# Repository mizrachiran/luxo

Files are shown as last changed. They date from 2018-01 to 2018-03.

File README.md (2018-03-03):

# luxo switch

The luxo switch is an ESP8266 based switch which can control up to 2 appliances.
It was design to be integrate in existing setups where the module can be hidden behind existing wall switches to control light or outlets.
The board support 90-240v input and outputs.

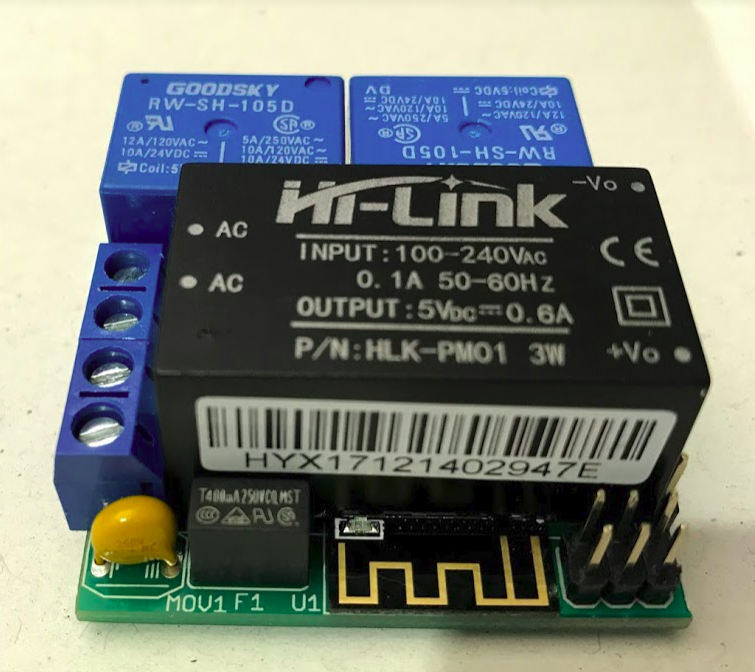
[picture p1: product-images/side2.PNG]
Luxo 1


[See more images](https://github.com/mizrachiran/luxo/tree/master/product-images)

# Software

Luxo support the following software:
* [Supla](https://www.supla.org/en/) - free cloud based open source software (offers ios & android apps)
* [Tasmota](https://github.com/arendst/Sonoff-Tasmota) - firmeware for controlling over MQTT

However, You can customize any ESP8266 open source project to work with the luxo switch

# Specification

* ESP8266 (ESP12E) WLAN module
* Wi-Fi 2.4GHz 802.11 b/g/n
* 90-240V I / O
* 2x outputs 10A, L switched
* 2x button connectors (to connect on \ off switches)
* Tempreture sensor input (DS18B20, DHT11 or DHT22)
* 1 ADC measurement input, e.g light intensity measurement from photoresistor
* 1 CFG button to enable the module into the configuration mode or assign custom action via software.
* 1 status LED
* Programming header pins (TX, RX, RST, 3.3v, GPIO0, GND)
* Size - 42 x 43 x 22 mm

# Schematic

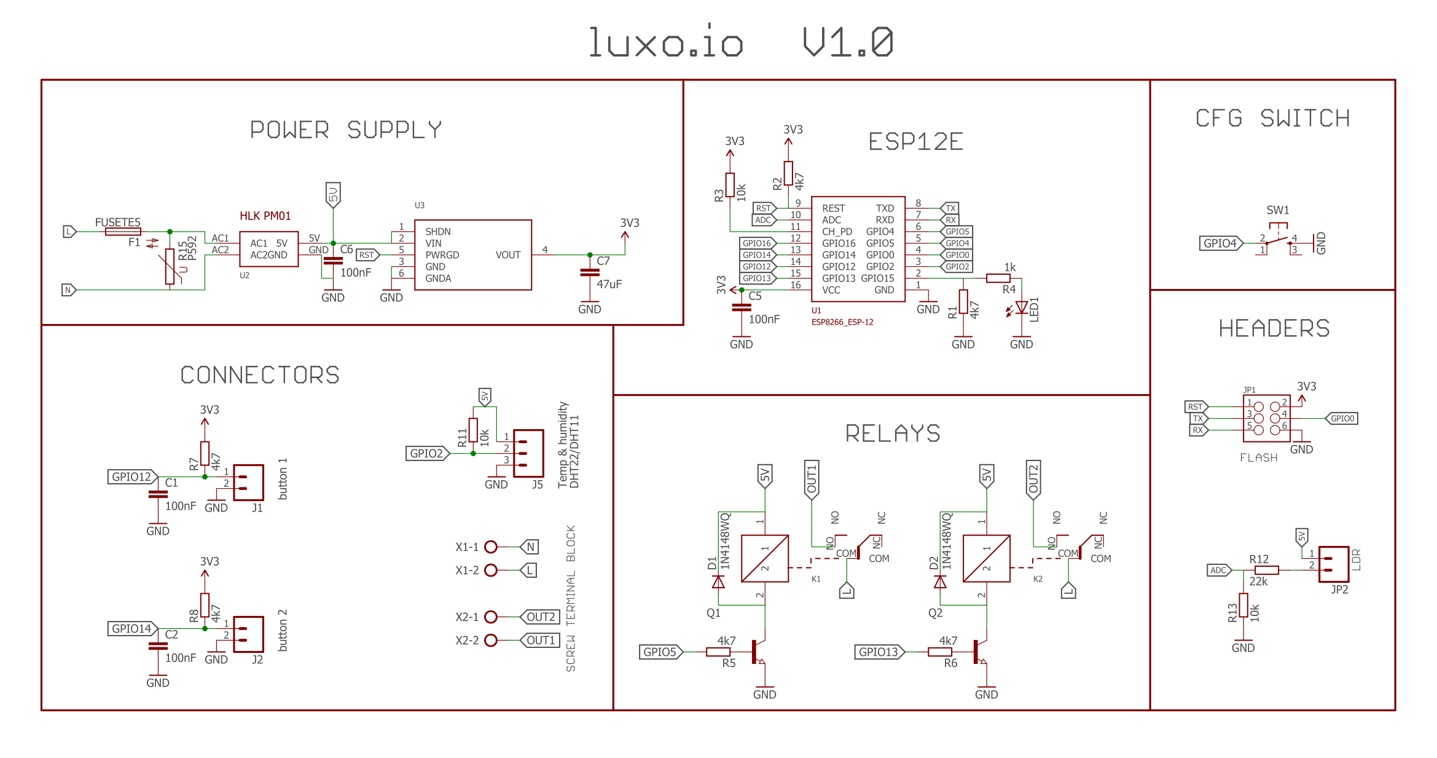
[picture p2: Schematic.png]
Luxo schematic


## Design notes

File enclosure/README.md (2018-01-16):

# Enclosure

[Open in Autodesk viewer](http://autode.sk/2DDgIPi)

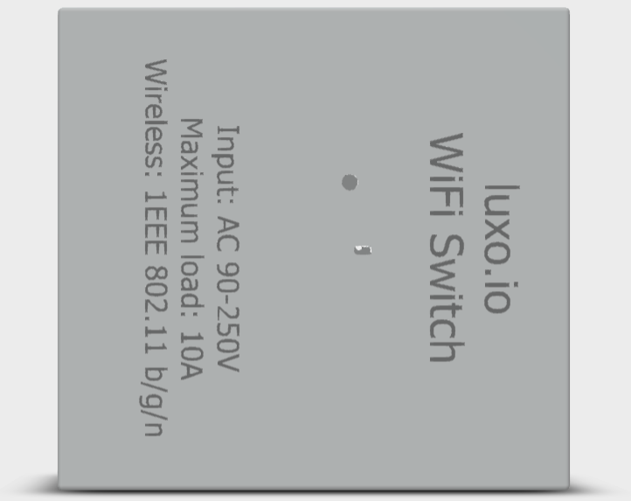
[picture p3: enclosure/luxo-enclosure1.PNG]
Luxo enclosure 1

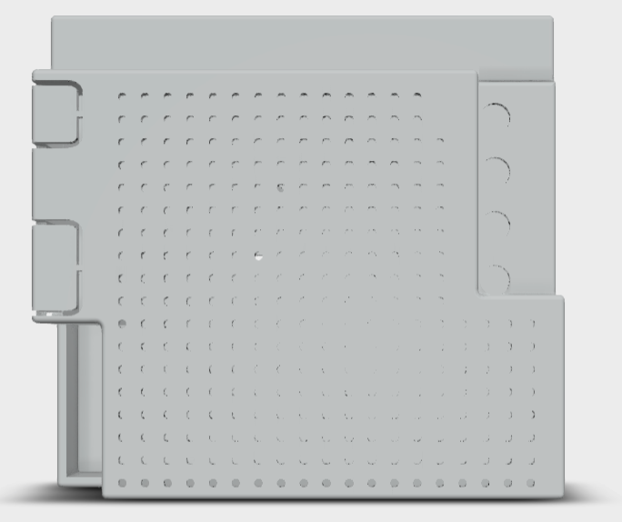
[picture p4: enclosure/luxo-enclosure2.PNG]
Luxo enclosure 2

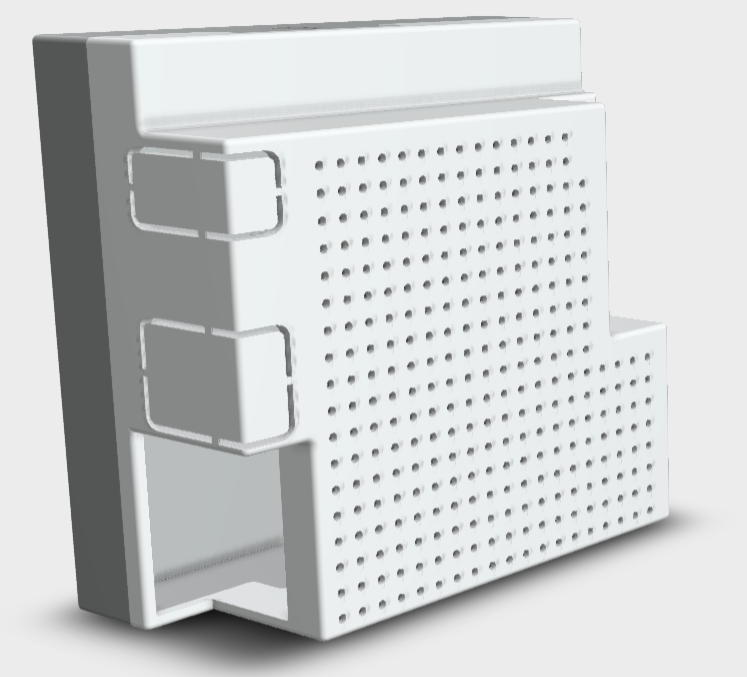
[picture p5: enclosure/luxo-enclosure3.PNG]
Luxo enclosure 3

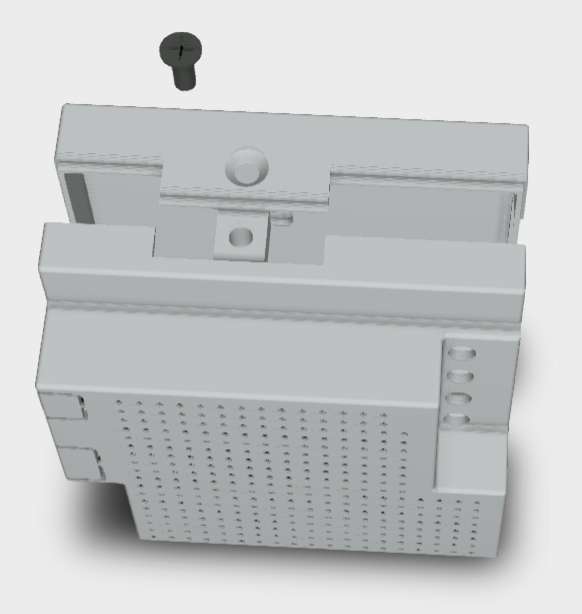
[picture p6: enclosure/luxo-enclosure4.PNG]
Luxo enclosure 4


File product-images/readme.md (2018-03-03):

# Images

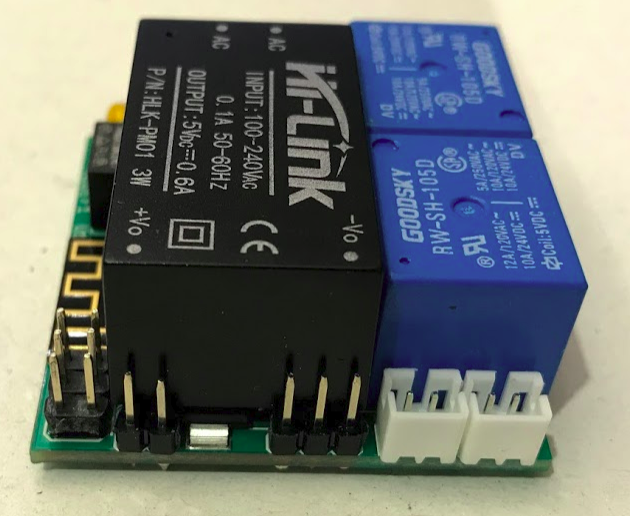
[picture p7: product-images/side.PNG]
Side 1

Side 2
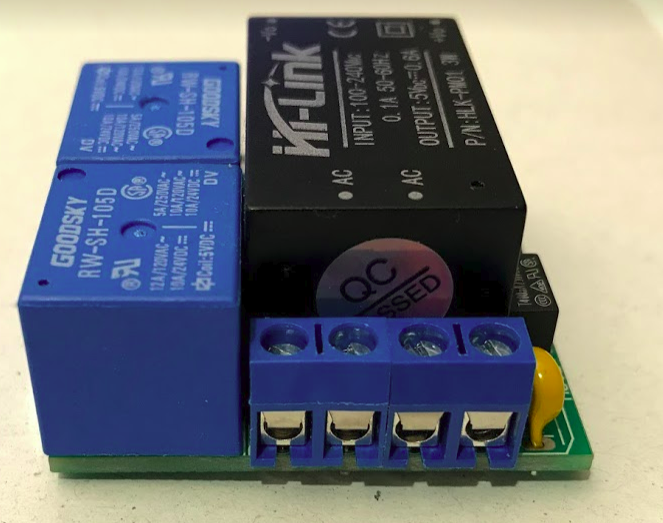
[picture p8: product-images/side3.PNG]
Side 3

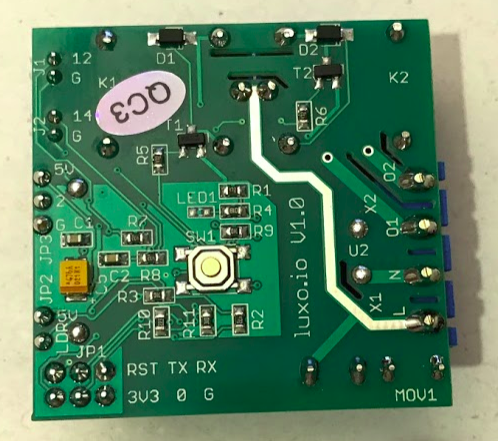
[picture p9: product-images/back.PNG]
Back 1

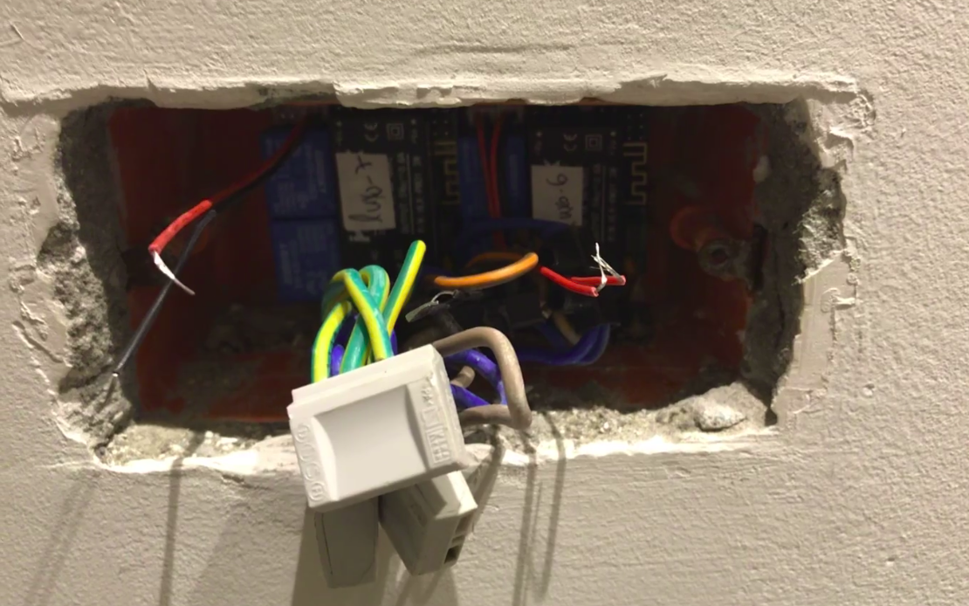
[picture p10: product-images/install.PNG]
Install 1


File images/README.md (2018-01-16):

# Images

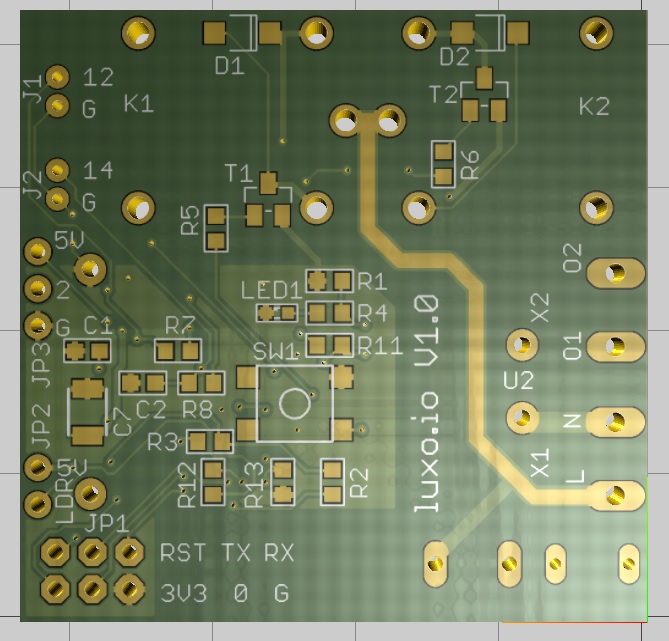
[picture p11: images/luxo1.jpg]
Luxo 1

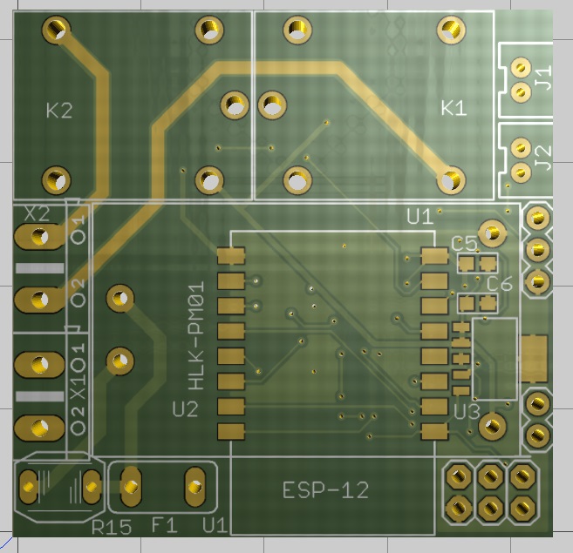
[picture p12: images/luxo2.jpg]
Luxo 2

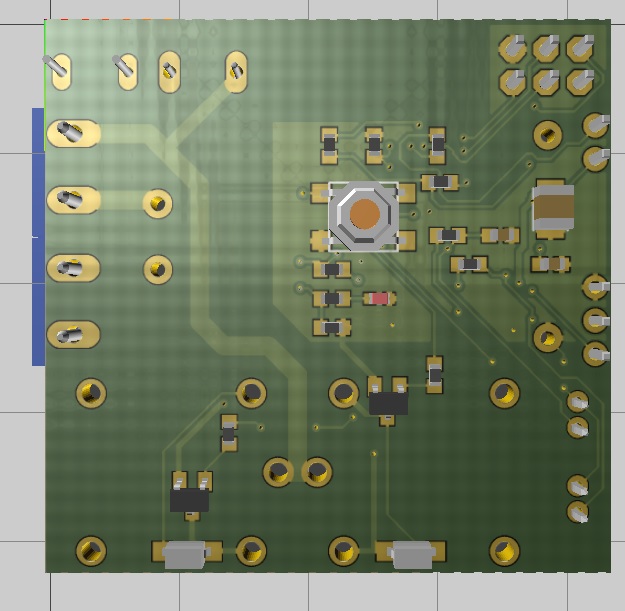
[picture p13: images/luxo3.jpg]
Luxo 3

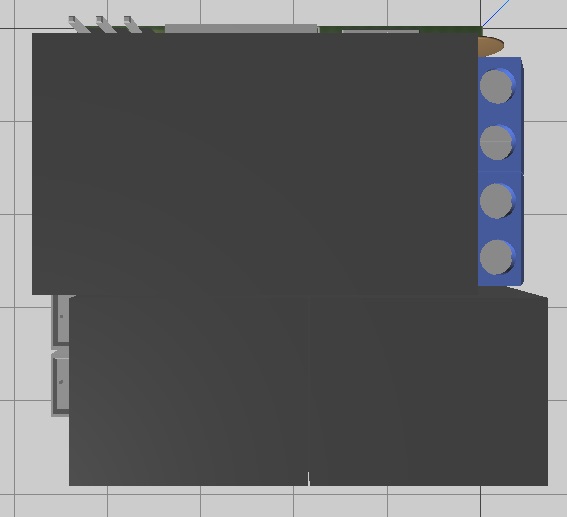
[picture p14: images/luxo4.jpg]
Luxo 4

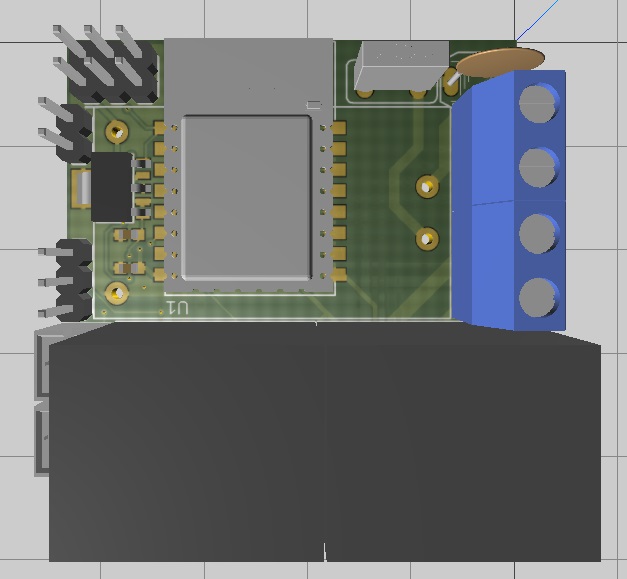
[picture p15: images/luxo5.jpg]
Luxo 5

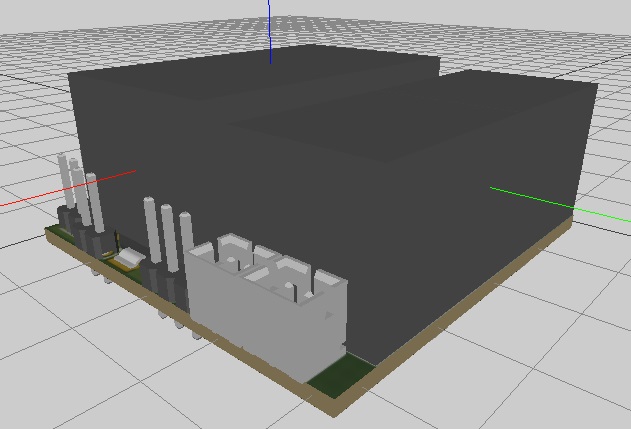
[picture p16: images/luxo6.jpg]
Luxo 6

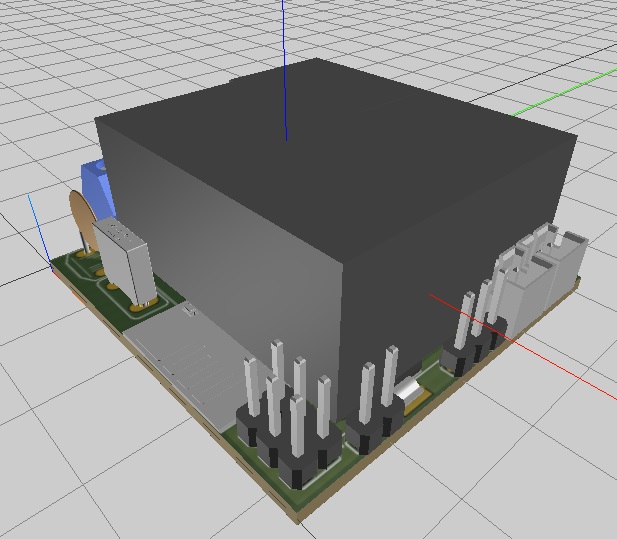
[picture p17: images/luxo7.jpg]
Luxo 7

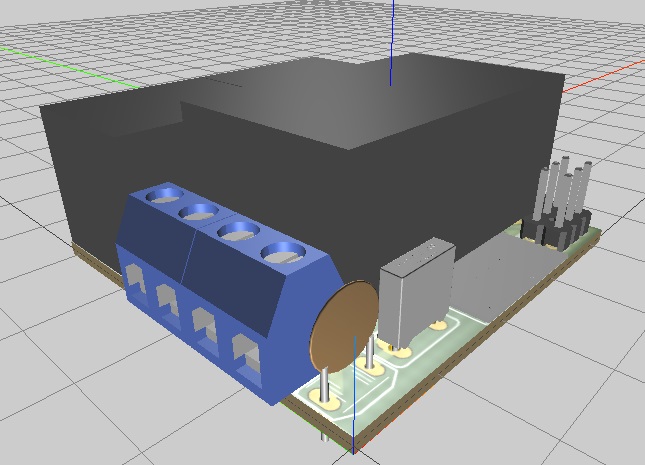
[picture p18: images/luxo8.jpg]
Luxo 8

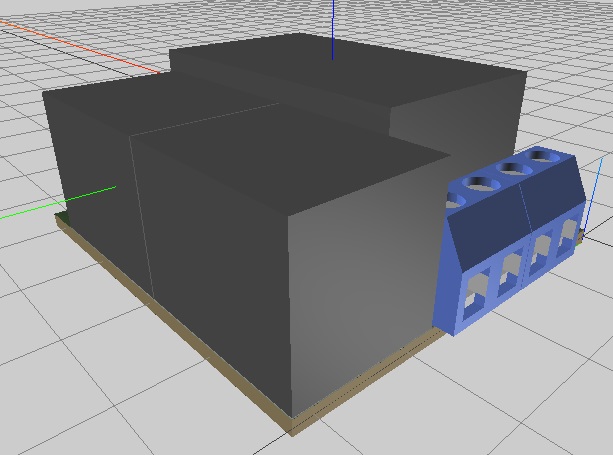
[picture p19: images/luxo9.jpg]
Luxo 9


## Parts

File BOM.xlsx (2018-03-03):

S/N | Ref Des | Quantity | Manufacturer | Part name/no. | Description | Package | Type | Source
1 | C1,C2,C3,C4 | 4 | Yageo | CC0603KRX7R9BB104 | 100nF smd capacitors | C0603 | SMT | mouser (https://www.mouser.com/ProductDetail/?qs=vTakOoo5QyLvVCYM2ge8LQ%3D%3D)
2 | C5 | 1 | AVX | F931C476MBAAJ6 | 47uF smd tantalum capacitor | C1210 | SMT | mouser (https://www.mouser.com/ProductDetail/AVX/F931C476MBAAJ6/)
3 | D1,D2 | 2 | Diodes INC | 1N4148W-7-F | General purpose smd diode | SOD123 | SMT | mouser (https://www.mouser.com/productdetail/diodes-incorporated/1n4148w-7-f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)
4 | F1 | 1 | multicomp | MST 400MA 250V | 450mA 250VAC fuse | TE5 | THT | element14 (http://uk.farnell.com/multicomp/mst-400ma-250v/fuse-radial-slow-blow-0-4a/dp/1566096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)
5 | J1,J2 | 2 | JST | B2B-PH-K-S(LF)(SN) | 2mm pitch 2pin connector | JST-2-PTH | THT | digikey (https://www.digikey.com/products/en?mpart=B2B-PH-K-S%28LF%29%28SN%29&v=455)
6 | JP1 | 1 | generic |  | 0.1" pitch male headers | 2x3 | THT
7 | JP2 | 1 | generic |  | 0.1" pitch male headers | 1x2 | THT
8 | JP3 | 1 | generic |  | 0.1" pitch male headers | 1x3 | THT
9 | K1,K2 | 2 | Goodsky | RW-SH-105D | 5V 10A relays | RW-SH | THT | goodsky (http://www.goodsky.com.tw/en/relays/general-purpose-relay/74-rw-rwh-relay)
10 | R1,R2,R5,R6,R7,R8 | 6 | Yageo | RC0603FR-074K7L | 4k7 smd resistors | R0603 | SMT | mouser (https://www.mouser.com/productdetail/yageo/rc0603fr-074k7l)
11 | R3,R9,R11 | 3 | Yageo | RC0603FR-0710KA | 10k smd resistors | R0603 | SMT | mouser (https://www.mouser.com/productdetail/yageo/rc0603fr-0710ka)
12 | R4 | 1 | Yageo | AT0603DRD071KL | 1k smd resistor | R0603 | SMT | mouser (https://www.mouser.com/productdetail/yageo/at0603drd071kl)
13 | R10 | 1 | Yageo | RC0603JR-0722KL | 22k smd resistor | R0603 | SMT | mouser (https://www.mouser.com/productdetail/yageo/rc0603jr-0722kl)
14 | MOV1 | 1 | Vishay | VDRS05C250BSE | varistor | 5mm pitch | THT | mouser (https://www.mouser.com/ProductDetail/Vishay/VDRS05C250BSE/?qs=wiLF9HC8rHZuKnB5wGgKng%3d%3d)
15 | SW1 | 1 | generic | mini pushbutton | smd tactile switch | BT4x4 | SMT | sparkfun (https://www.sparkfun.com/products/8720)
16 | T1,T2 | 2 | diodes inc | BC817-40Q-7-F | general purpose smd transistor | SOT23-3 | SMT | mouser (https://www.mouser.com/productdetail/diodes-incorporated/bc817-40q-7-f)
17 | U1 | 1 | Adafruit | 2491 | ESP12E wifi module |  | SMT | element14 (http://www.newark.com/adafruit/2491/esp8266-smt-module-esp-12e/dp/77Y5210) | also see this one (https://www.adafruit.com/product/2491)
18 | U2 | 1 | hi-link | HLK-PM01 | smps output- 5V 3W |  | THT | hilink (http://www.hlktech.net/product_detail.php?ProId=54)
19 | U3 | 1 | Microchip | MCP1825T-3302E/DC | 3.3V voltage regulator | SOT223-5 | SMT | microchip (http://www.microchip.com/wwwproducts/en/MCP1825)
20 | X1,X2 | 2 | generic | AK500-2 | screw type terminal block | AK500-2 | THT | pololu (https://www.pololu.com/product/2440)

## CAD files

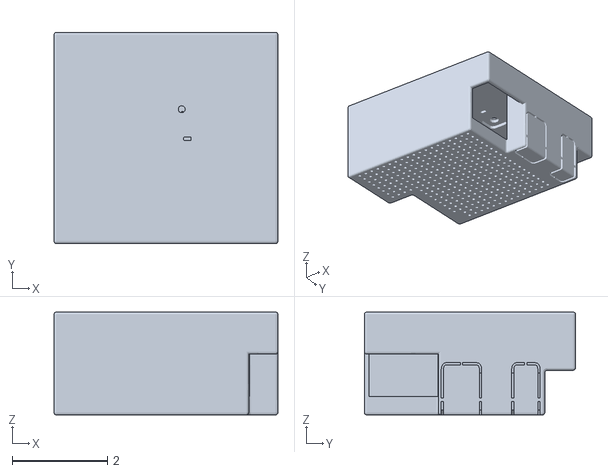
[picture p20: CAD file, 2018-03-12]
enclosure/30-000001 Enclousure Assembly.stl
4.71 x 4.44 x 2.17

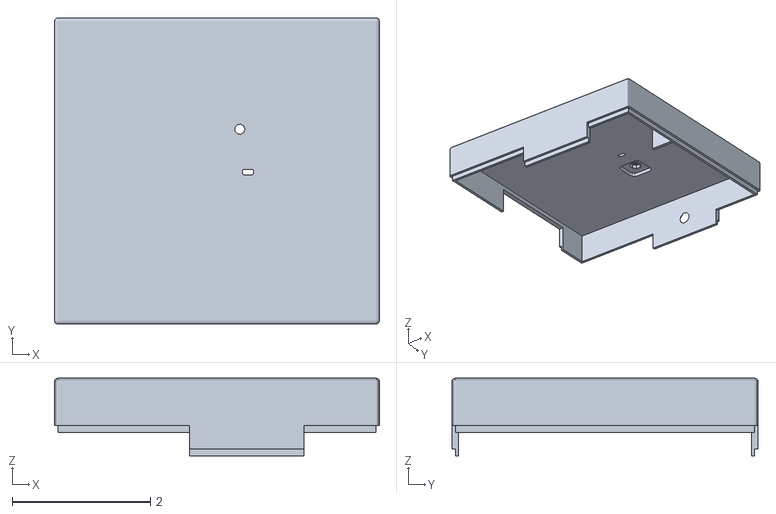
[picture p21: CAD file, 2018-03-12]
enclosure/Bottom - Without text.stl
4.71 x 4.44 x 1.12

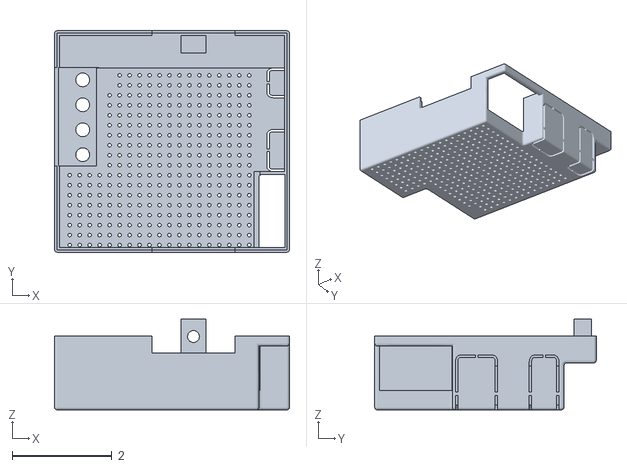
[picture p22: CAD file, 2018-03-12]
enclosure/Top.stl
4.71 x 4.44 x 1.82

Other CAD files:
enclosure/Button.stl

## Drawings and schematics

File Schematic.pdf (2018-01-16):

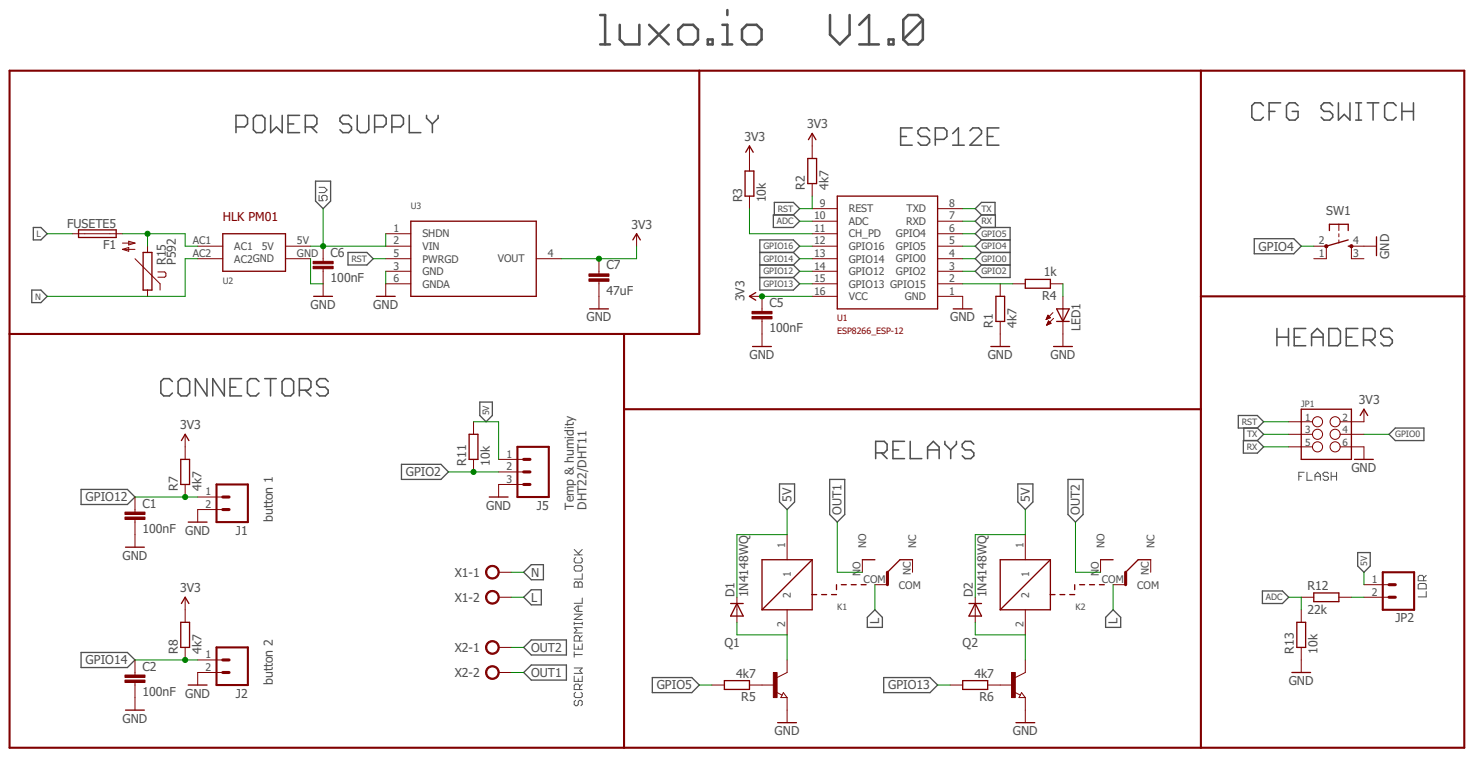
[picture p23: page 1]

button 1 button 2 Temp & humidity DHT22/DHT11 GND 3V3 4k7 4k7 10k GND 3V3 3V3 1kGND 1N4148WQ 1N4148WQ GND GND 4k7 4k7 GND GND GND4k7 4k7 3V3 3V3 100nF 100nF 10k GND GND 22k10k GND P592 FUSETE5 100nF GND GND GND 100nF GND GND 3V3 47uF GND 3V3 GND 1 GPIO15 2 GPIO2 3 GPIO0 4 GPIO5 5 GPIO4 6 RXD 7 TXD 8 REST 9 ADC 10 CH_PD 11 GPIO16 12 GPIO14 13 GPIO12 14 GPIO13 15 VCC 16 R1 R2 R3 LED1 R4 1 1 2 2 NO NO NC NC COM COM K1 1 1 2 2 NO NO NC NC COM COM K2 D1D2 Q1 Q2 R5 R6 SW1 2 4 1 3 J1 12 J2 12 R7 R8 C1C2 J5 123 R11 X1-1 X1-2 X2-1 X2-2 JP11 2 3 4 5 6 R12 R13 5V 5V GND GND AC1 AC1 AC2 AC2 U2 R1F1 5 C5 SHDN 1 VIN 2 PWRGD 5 GND 3 GNDA 6 VOUT 4 U3 C6 C7 JP2 12 TX TX RX RX GPIO5 GPIO5 GPIO4 GPIO4 GPIO0 GPIO0 GPIO2 GPIO2 RST RST RST ADC ADC GPIO16 GPIO14 GPIO14 GPIO12 GPIO12 GPIO13 GPIO13 5V5V 5V 5V LL L L N N OUT1 OUT1 OUT2 OUT2 ESP8266_ESP-12 U1 HLK PM01

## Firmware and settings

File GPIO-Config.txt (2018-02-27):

GPIO0 - Flash jumper
GPIO2 - Sensor (e.g. DHT22 \ DHT11)
GPIO4 - CFG Button
GPIO5 - Relay D1
GPIO12 - Button 1
GPIO13 - Relay D2
GPIO14 - Button 2
GPIO15 - Status LED
